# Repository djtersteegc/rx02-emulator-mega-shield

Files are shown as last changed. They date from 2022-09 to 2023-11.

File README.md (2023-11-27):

# rx02-emulator-mega-shield

Arduino Mega2560 shield with buttons and LCD based on [AK6DN's DEC RX02 emulator](https://github.com/AK6DN/rx02_emulator) board design and code.  There is a fork of his project at  https://github.com/djtersteegc/rx02_emulator that adds software support for the new board design.

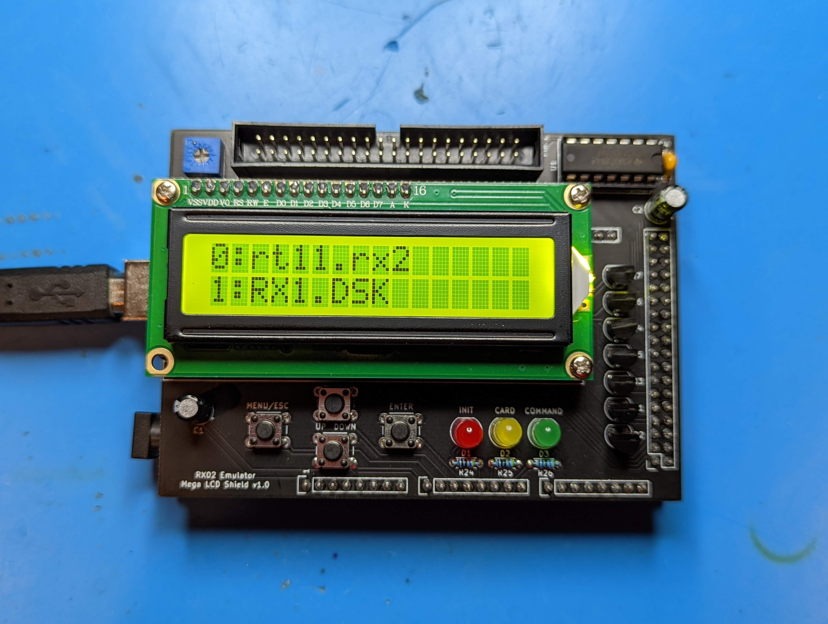
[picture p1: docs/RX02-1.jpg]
rx02-1


You can also still run it via the original serial terminal command scheme.  If you don't want to build it with the LCD or buttons, you can disable supprort in the code by leaving

`#define USE_LCD_MENU`

commented out (undefined) in `my_project.h`

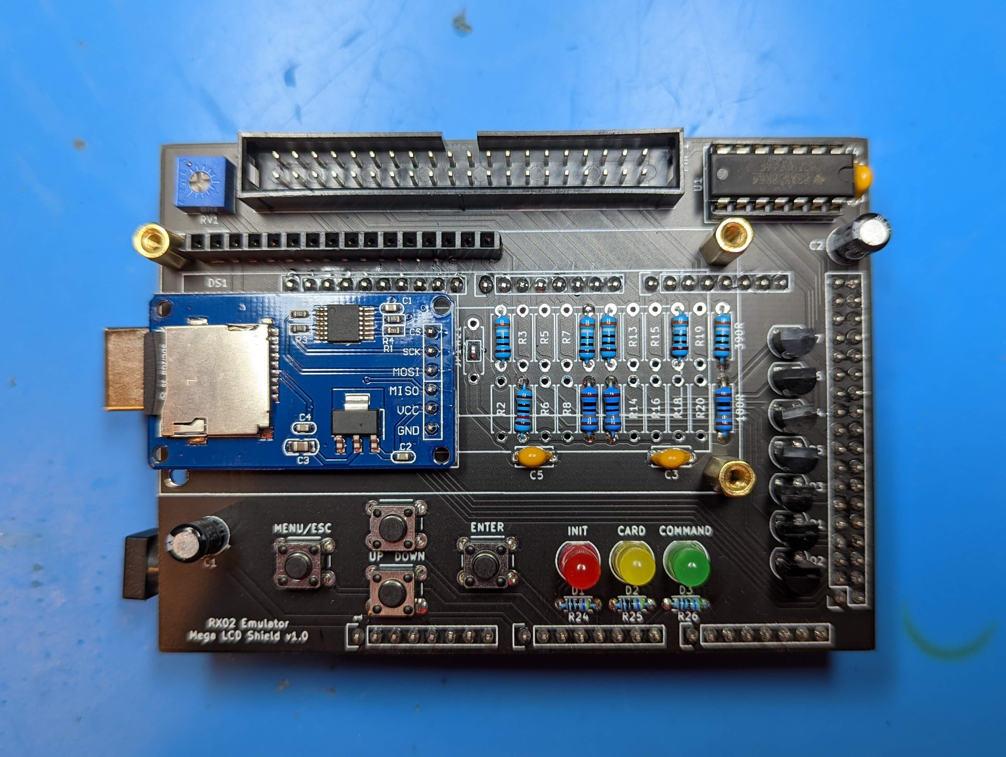
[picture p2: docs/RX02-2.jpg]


Resistor numbers is also different than AK6DN's original board so please refer to this mapping table below or the CSV file.

[Termination Resistor Table.csv](https://github.com/djtersteegc/rx02-emulator-mega-shield/blob/main/Termination%20Resistor%20Table.csv)

Most of the resistor footprints should NOT be populated.

| Signal | Resistor | Value | Resistor | Value |
| --- | --- | --- | --- | --- |
| RX_DMA_MODE_H  | R2 | - | R1 | **390** |
| RX_AC_L | R4 | **120** | R3 | - |
| RX_OUT_L | R6 | - | R5 | - |
| RX_SHIFT_L | R8 | - | R7 | - |
| RX_12BIT_L | R10 | **180** | R9 | **390** |
| RX_DATA_L | R12 | **180** | R11 | **390** |
| RX_DONE_L | R14 | - | R13 | - |
| RX_XFER_RQST_L | R16 | - | R15 | - |
| RX_INIT_L | R18 | - | R17 | **390** |
| RX_ERROR_L | R20 | - | R19 | - |
| RX_RUN_L | R23 | **180** | R22 | **390** |

STL's and the [DesignSpark Mechanical](https://www.rs-online.com/designspark/mechanical-software) source file for an snap fit enclosure are in the **enclosure** directory. There is also a provision to secure it with one M3x6mm (or longer) screw if you want.  Since the power and USB port spacing on the Chinese clone Arduino Mega2560's with the CH340 serial chip is different than the original design there are two STL's for the case body, pick the one that matches your board.

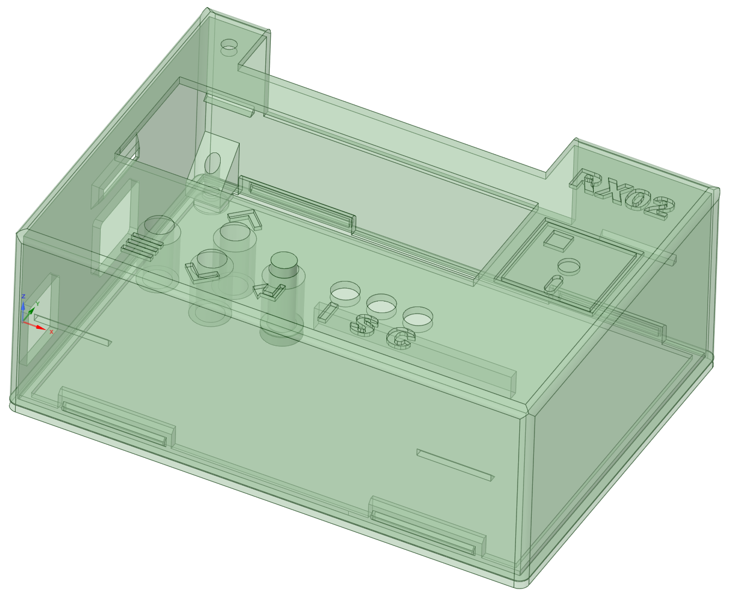
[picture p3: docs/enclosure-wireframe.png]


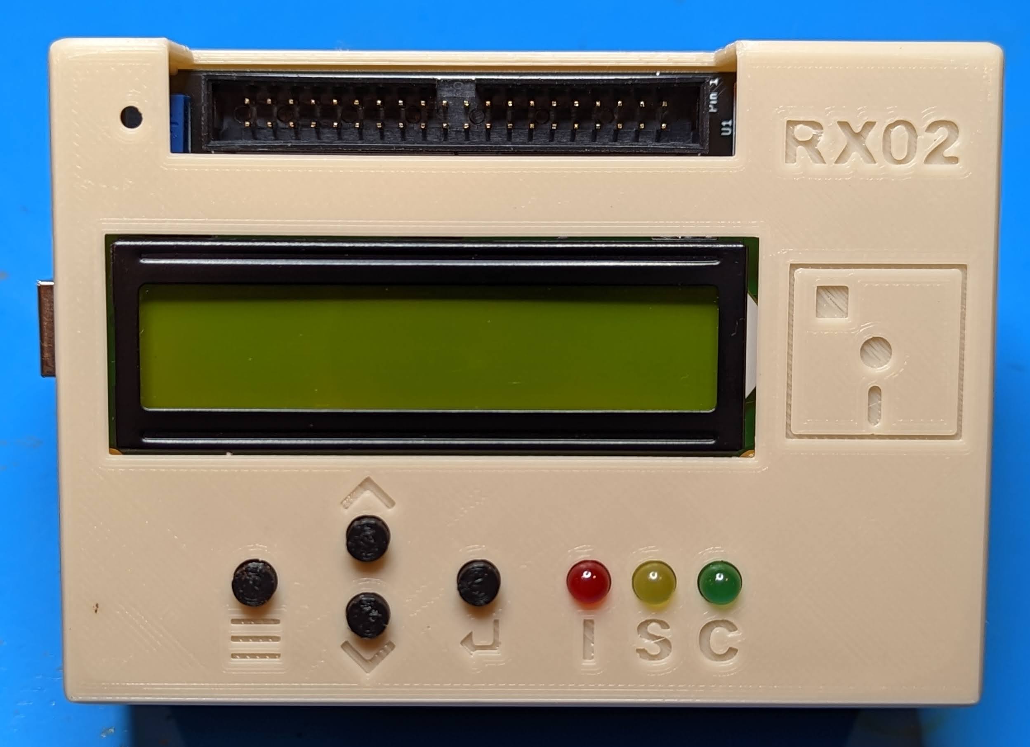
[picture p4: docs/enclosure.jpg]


All components can be sourced from the usual low cost China based vendors for a total build cost of around $20.  Please see the assembly page for more details.

[Hardware Component Choices and Assembly](https://djtersteegc.github.io/rx02-emulator-mega-shield/assembly.html)

An interactive BOM and parts placement diagram is also available.

[Interactive Bill of Materials (BOM)](https://djtersteegc.github.io/rx02-emulator-mega-shield/ibom.html)

# Getting a Board

You can download the Gerbers and use your favorite fab (JLCPCB, PCBWay, etc.) to make your own batch.  It's a standard two layer, 1oz copper board with dimensions of 99mm x 71mm so it squeaks under the 100mm x 100mm limit of the cheap Chinese fabs.

# Hardware Revisions

### Version 1.0

After designing and building the [Mega Pro SMD](https://github.com/djtersteegc/rx02-mega2560-pro) version of this, I discovered the reason you always had to do a ReINIT of the emulator to get it recognized was I failed to pick interrupt enabled pins on the Mega2560 for the RX_INIT and RX_RUN lines.  This has been corrected in the v1.1 board and you can fix this yourself in v1.0 by adding two jumper  wires from D22 to D2, and D26 to D3.  Once complete, reflash with the updated version of the code at https://github.com/djtersteegc/rx02_emulator 

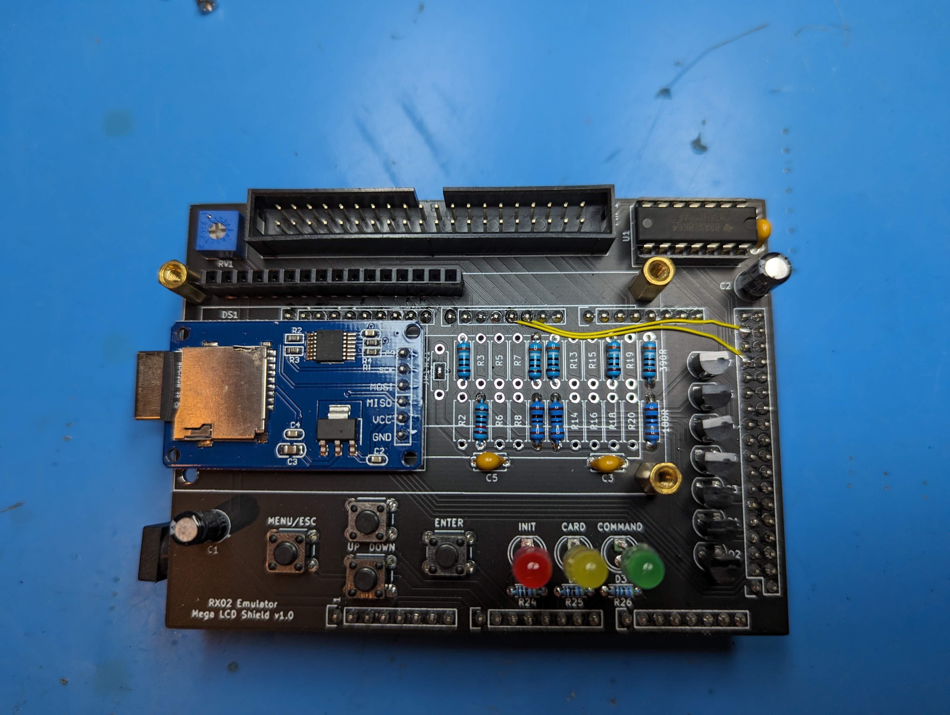
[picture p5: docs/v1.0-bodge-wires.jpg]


### Version 1.1

Moved the RX_INIT and RX_RUN lines to interrupt enabled pins on the Mega2560.

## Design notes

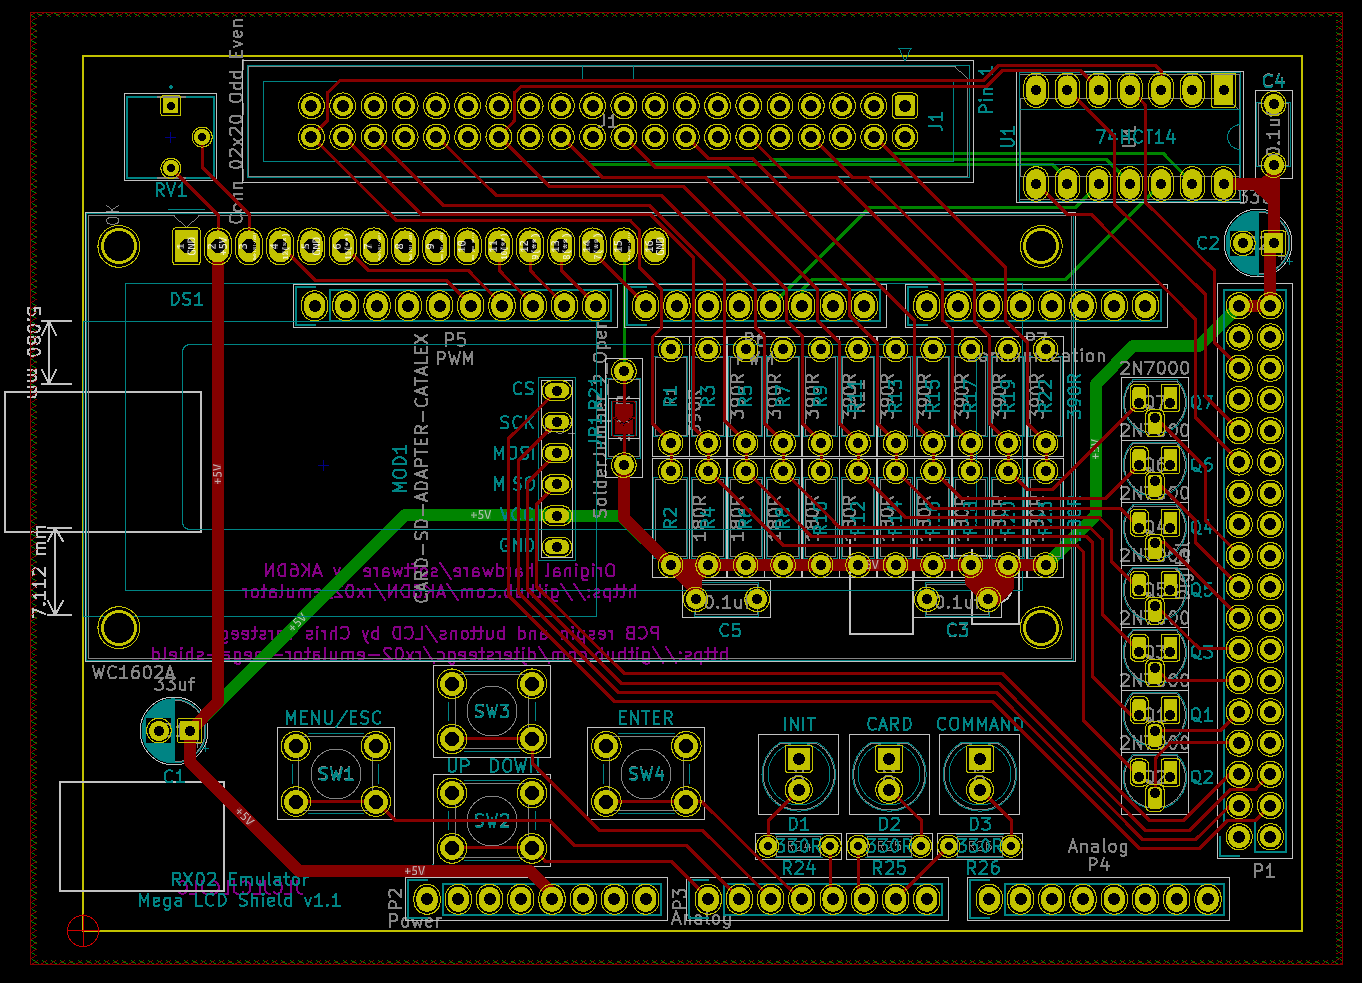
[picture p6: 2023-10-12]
Board v1.1.PNG

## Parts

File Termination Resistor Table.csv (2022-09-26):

Signal | Original Boards | LCD Board | Value
RX_DMA_MODE_H | R2 | R2 | -
 | R3 | R1 | 390
RX_AC_L | R4 | R4 | 120
 | R5 | R3 | -
RX_OUT_L | R6 | R6 | -
 | R7 | R5 | -
RX_SHIFT_L | R8 | R8 | -
 | R9 | R7 | -
RX_12BIT_L | R10 | R10 | 180
 | R23 | R9 | 390
RX_DATA_L | R11 | R12 | 180
 | R12 | R11 | 390
RX_DONE_L | R13 | R14 | -
 | R14 | R13 | -
RX_XFER_RQST_L | R15 | R16 | -
 | R16 | R15 | -
RX_INIT_L | R17 | R18 | -
 | R18 | R17 | 390
RX_ERROR_L | R19 | R20 | -
 | R20 | R19 | -
RX_RUN_L | R21 | R23 | 180
 | R22 | R22 | 390

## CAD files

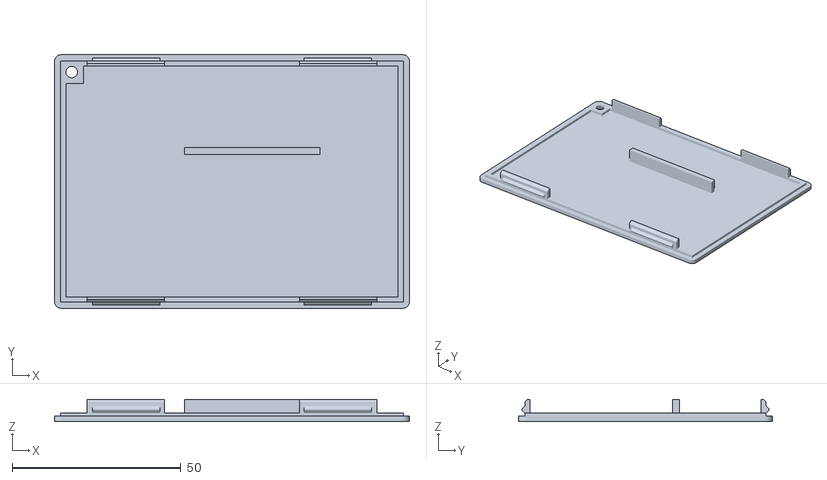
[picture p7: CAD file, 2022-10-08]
enclosure/rx02 lid.stl
105.2 x 75.1 x 6.60

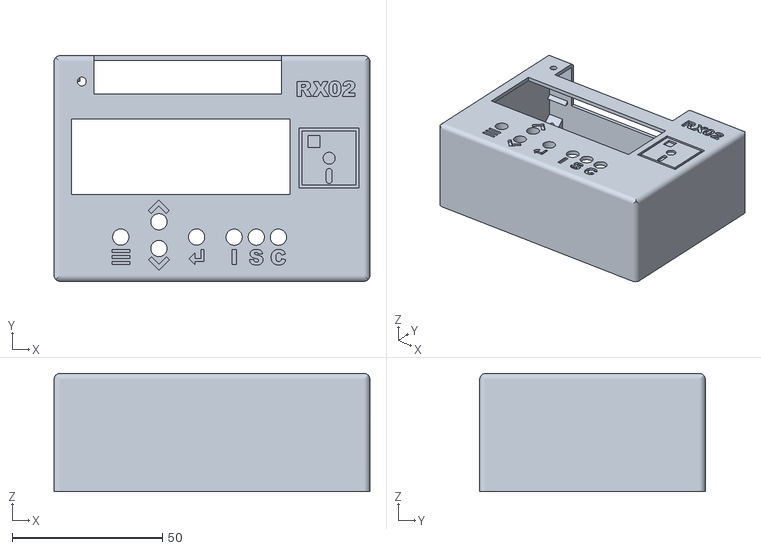
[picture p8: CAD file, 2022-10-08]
enclosure/rx02 body.stl
105.2 x 75.1 x 39.3

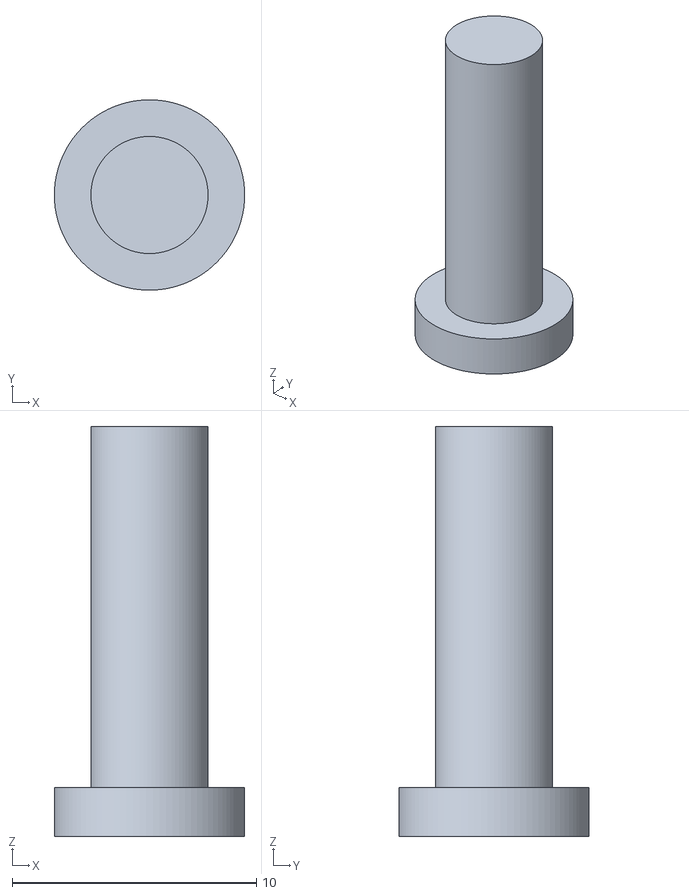
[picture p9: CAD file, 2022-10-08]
enclosure/rx02 button.stl
7.80 x 7.80 x 16.8

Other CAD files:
enclosure/rx02 body - ch340 clone.stl

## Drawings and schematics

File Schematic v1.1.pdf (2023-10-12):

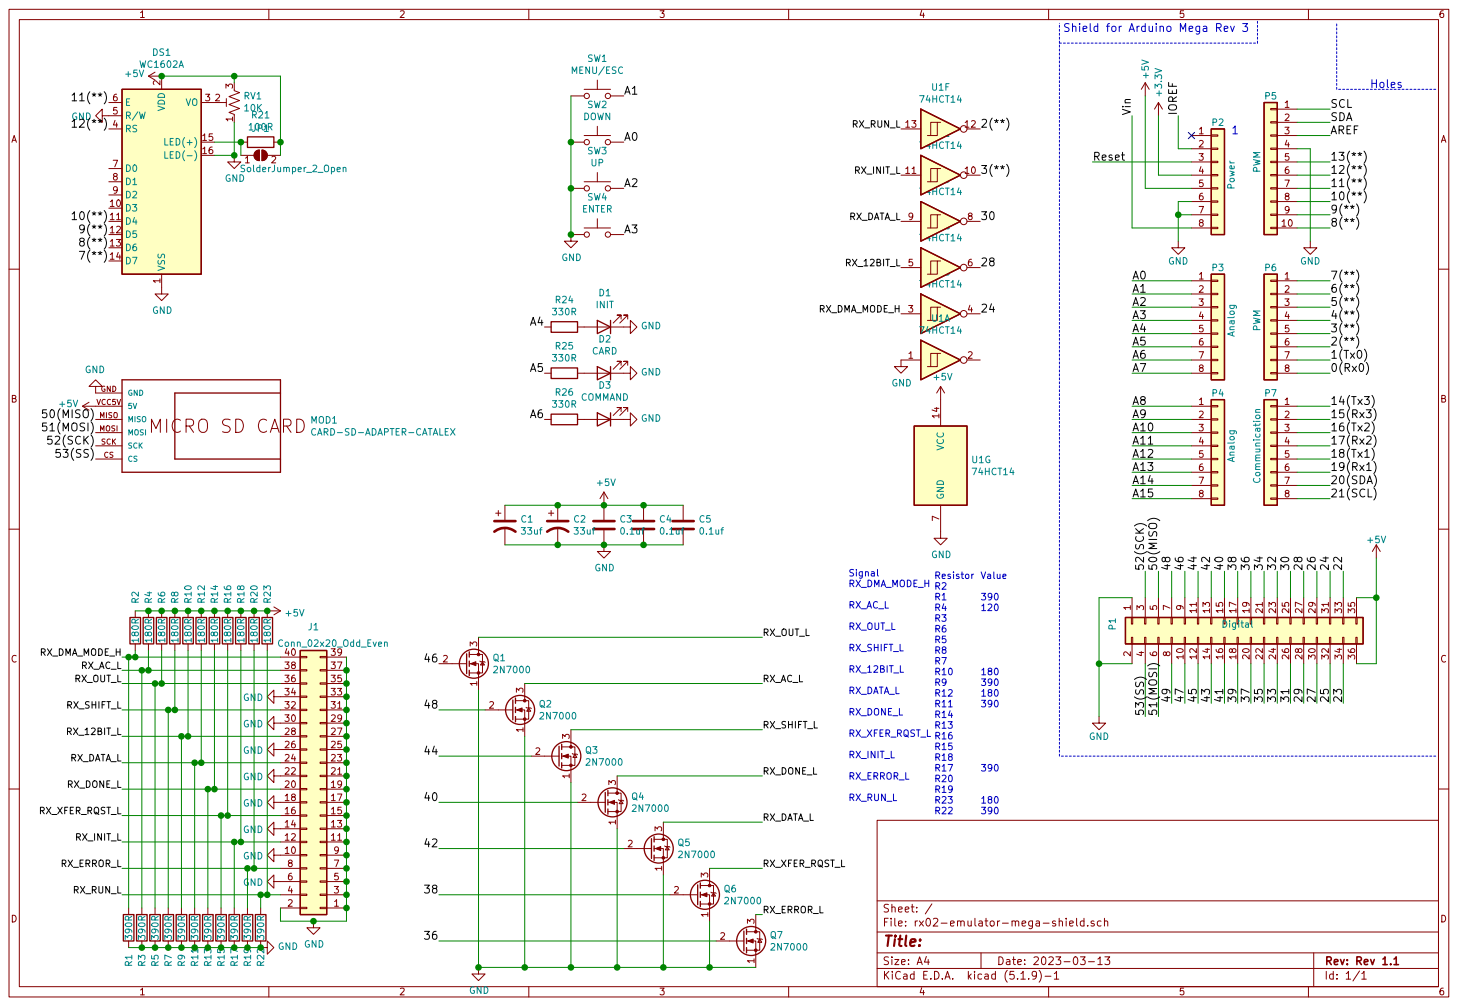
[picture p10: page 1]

38 | 37
36 | 35
34 | 33

File: rx02-emulator-mega-shield.sch Sheet: /
Id: 1/1 Title:

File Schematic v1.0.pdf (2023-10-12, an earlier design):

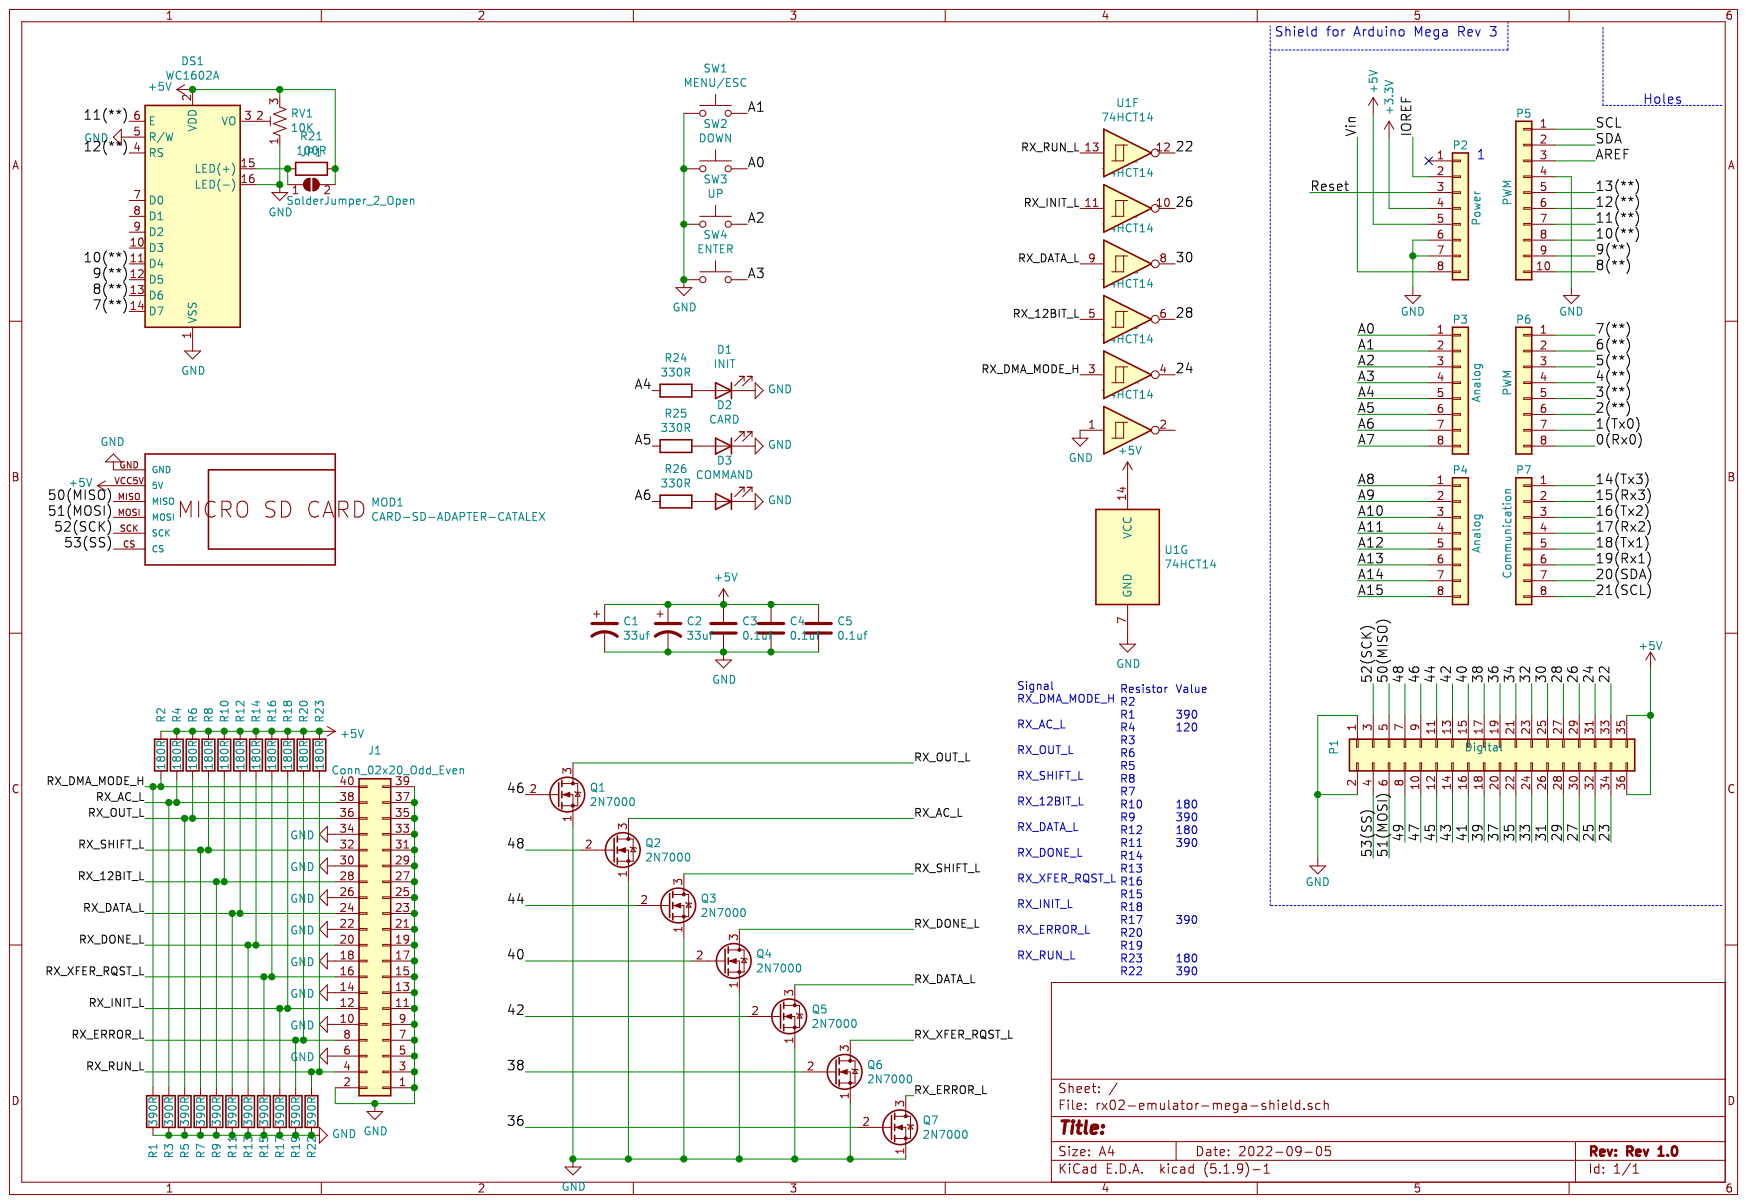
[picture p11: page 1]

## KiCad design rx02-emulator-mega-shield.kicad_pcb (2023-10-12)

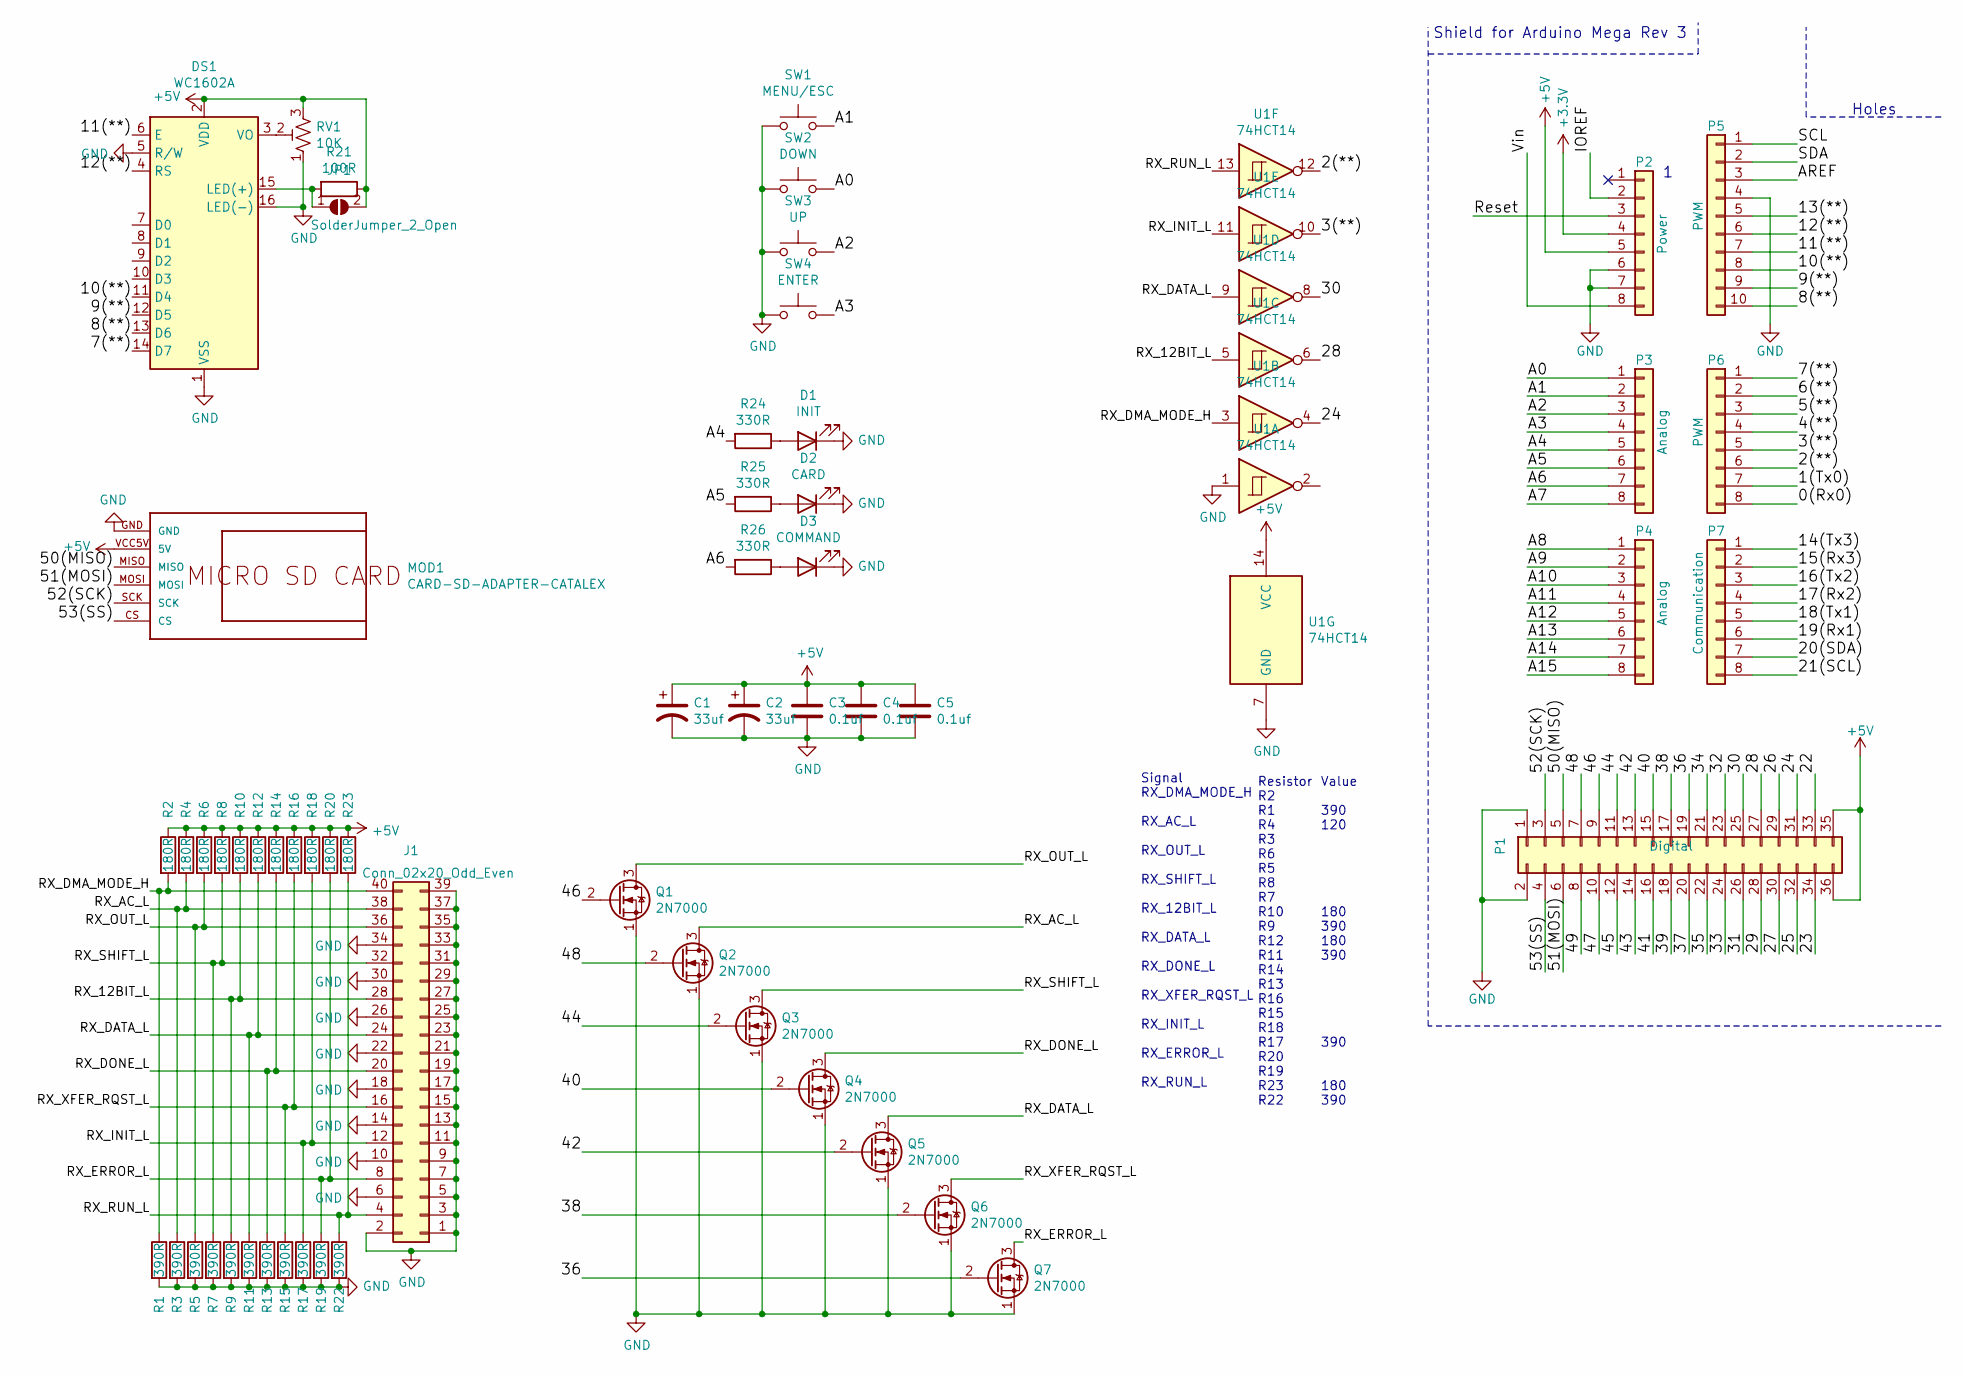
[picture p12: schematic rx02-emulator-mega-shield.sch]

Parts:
C1, C2: 33uf; CP_Radial_D5.0mm_P2.50mm
C3, C4, C5: 0.1uf; C_Disc_D5.0mm_W2.5mm_P5.00mm
D1: INIT; LED_D5.0mm
D2: CARD; LED_D5.0mm
D3: COMMAND; LED_D5.0mm
DS1: WC1602A
J1: Conn_02x20_Odd_Even; IDC-Header_2x20_P2.54mm_Vertical
JP1: SolderJumper_2_Open; SolderJumper-2_P1.3mm_Open_TrianglePad1.0x1.5mm
MOD1: CARD-SD-ADAPTER-CATALEX; Catalex-MicroSD-Card-Up
P1: Digital; Socket_Strip_Arduino_2x18
P2: Power; Socket_Strip_Arduino_1x08
P3, P4: Analog; Socket_Strip_Arduino_1x08
P5: PWM; Socket_Strip_Arduino_1x10
P6: PWM; Socket_Strip_Arduino_1x08
P7: Communication; Socket_Strip_Arduino_1x08
Q1, Q2, Q3, Q4, Q5, Q6, Q7: 2N7000; TO-92_HandSolder
R1, R3, R5, R7, R9, R11, R13, R15, R17, R19, R22: 390R; R_Axial_DIN0207_L6.3mm_D2.5mm_P7.62mm_Horizontal
R2, R4, R6, R8, R10, R12, R14, R16, R18, R20, R23: 180R; R_Axial_DIN0207_L6.3mm_D2.5mm_P7.62mm_Horizontal
R21: 100R; R_Axial_DIN0207_L6.3mm_D2.5mm_P7.62mm_Horizontal
R24, R25, R26: 330R; R_Axial_DIN0204_L3.6mm_D1.6mm_P5.08mm_Horizontal
RV1: 10K; TRIM_3362P-1-103
SW1: MENU/ESC; SW_PUSH_6mm_H4.3mm
SW2: DOWN; SW_PUSH_6mm_H4.3mm
SW3: UP; SW_PUSH_6mm_H4.3mm
SW4: ENTER; SW_PUSH_6mm_H4.3mm
U1: 74HCT14; DIP-14_W7.62mm_Socket_LongPads

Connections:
+3V3: P2.4
+5V: C1.1, C2.1, C3.1, C4.1, C5.1, DS1.2 (VDD), JP1.2 (B), MOD1.VCC5V (5V), P1.35, P1.36, P2.5, R2.1, R4.1, R6.1, R8.1, R10.1, R12.1, R14.1, R16.1, R18.1, R20.1, R21.1, R23.1, RV1.3, U1.14 (VCC)
/0(Rx0): P6.8
/1(Tx0): P6.7
/2(**): P6.6, U1.12
/3(**): P6.5, U1.10
/4(**): P6.4
/5(**): P6.3
/6(**): P6.2
/7(**): DS1.14 (D7), P6.1
/8(**): DS1.13 (D6), P5.10
/9(**): DS1.12 (D5), P5.9
/10(**): DS1.11 (D4), P5.8
/11(**): DS1.6 (E), P5.7
/12(**): DS1.4 (RS), P5.6
/13(**): P5.5
/14(Tx3): P7.1
/15(Rx3): P7.2
/16(Tx2): P7.3
/17(Rx2): P7.4
/18(Tx1): P7.5
/19(Rx1): P7.6
/20(SDA): P7.7
/21(SCL): P7.8
/22: P1.33
/23: P1.34
/24: P1.31, U1.4
/25: P1.32
/26: P1.29
/27: P1.30
/28: P1.27, U1.6
/29: P1.28
/30: P1.25, U1.8
/31: P1.26
/32: P1.23
/33: P1.24
/34: P1.21
/35: P1.22
/36: P1.19, Q7.2 (G)
/37: P1.20
/38: P1.17, Q6.2 (G)
/39: P1.18
/40: P1.15, Q4.2 (G)
/41: P1.16
/42: P1.13, Q5.2 (G)
/43: P1.14
/44: P1.11, Q3.2 (G)
/45: P1.12
/46: P1.9, Q1.2 (G)
/47: P1.10
/48: P1.7, Q2.2 (G)
/49: P1.8
/50(MISO): MOD1.MISO, P1.5
/51(MOSI): MOD1.MOSI, P1.6
/52(SCK): MOD1.SCK, P1.3
/53(SS): MOD1.CS, P1.4
/A0: P3.1, SW2.2
/A1: P3.2, SW1.2
/A2: P3.3, SW3.2
/A3: P3.4, SW4.2
/A4: P3.5, R24.2
/A5: P3.6, R25.2
/A6: P3.7, R26.2
/A7: P3.8
/A8: P4.1
/A9: P4.2
/A10: P4.3
/A11: P4.4
/A12: P4.5
/A13: P4.6
/A14: P4.7
/A15: P4.8
/AREF: P5.3
/IOREF: P2.2
/RX_12BIT_L: J1.28, R9.1, R10.2, U1.5
/RX_AC_L: J1.38, Q2.3 (D), R3.1, R4.2
/RX_DATA_L: J1.24, Q5.3 (D), R11.1, R12.2, U1.9
/RX_DMA_MODE_H: J1.40, R1.1, R2.2, U1.3
/RX_DONE_L: J1.20, Q4.3 (D), R13.1, R14.2
/RX_ERROR_L: J1.8, Q7.3 (D), R19.1, R20.2
/RX_INIT_L: J1.12, R17.1, R18.2, U1.11
/RX_OUT_L: J1.36, Q1.3 (D), R5.1, R6.2
/RX_RUN_L: J1.4, R22.1, R23.2, U1.13
/RX_SHIFT_L: J1.32, Q3.3 (D), R7.1, R8.2
/RX_XFER_RQST_L: J1.16, Q6.3 (D), R15.1, R16.2
/Reset: P2.3
/SCL: P5.1
/SDA: P5.2
/Vin: P2.8
GND: C1.2, C2.2, C3.2, C4.2, C5.2, D1.1 (K), D2.1 (K), D3.1 (K), DS1.1 (VSS), DS1.5 (R/W), DS1.16 (LED(-)), J1.1, J1.2, J1.3, J1.5, J1.6, J1.7, J1.9, J1.10, J1.11, J1.13, J1.14, J1.15, J1.17, J1.18, J1.19, J1.21, J1.22, J1.23, J1.25, J1.26, J1.27, J1.29, J1.30, J1.31, J1.33, J1.34, J1.35, J1.37, J1.39, MOD1.GND, P1.1, P1.2, P2.6, P2.7, P5.4, Q1.1 (S), Q2.1 (S), Q3.1 (S), Q4.1 (S), Q5.1 (S), Q6.1 (S), Q7.1 (S), R1.2, R3.2, R5.2, R7.2, R9.2, R11.2, R13.2, R15.2, R17.2, R19.2, R22.2, RV1.1, SW1.1, SW2.1, SW3.1, SW4.1, U1.1, U1.7 (GND)
unnamed: D1.2 (A), R24.1
unnamed: D2.2 (A), R25.1
unnamed: D3.2 (A), R26.1
unnamed: DS1.3 (VO), RV1.2
unnamed: DS1.15 (LED(+)), JP1.1 (A), R21.2

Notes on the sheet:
Shield for Arduino Mega Rev 3
Holes
Signal RX_DMA_MODE_H RX_AC_L RX_OUT_L RX_SHIFT_L RX_12BIT_L RX_DATA_L RX_DONE_L RX_XFER_RQST_L RX_INIT_L RX_ERROR_L RX_RUN_L
Resistor R2 R1 R4 R3 R6 R5 R8 R7 R10 R9 R12 R11 R14 R13 R16 R15 R18 R17 R20 R19 R23 R22
Value 390 120 180 390 180 390 390 180 390

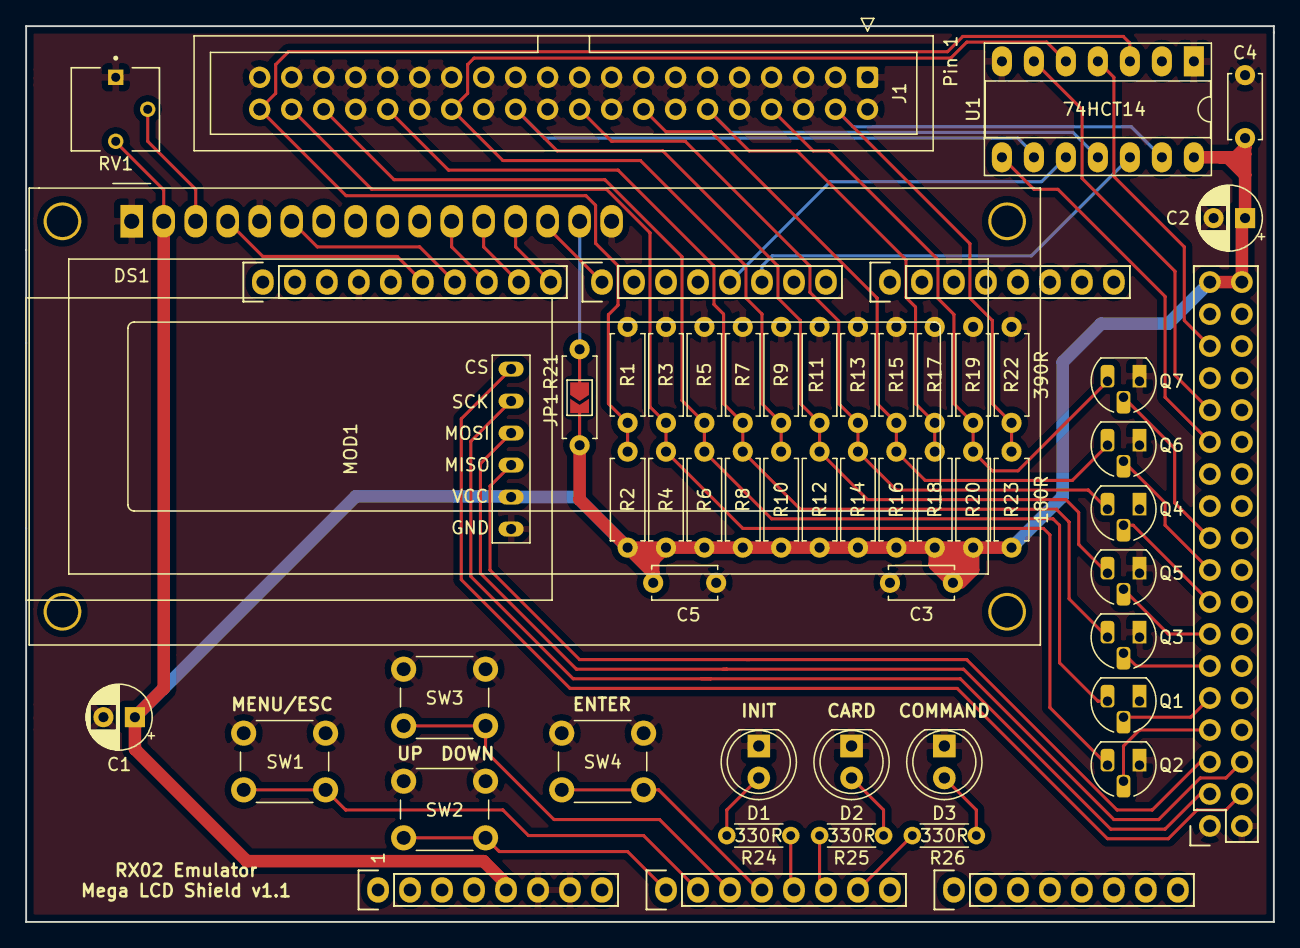
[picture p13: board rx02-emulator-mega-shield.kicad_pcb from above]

Board: 2 copper layers, 99.1 x 71.1 mm, 58 parts (0 on the bottom side), 47 nets.

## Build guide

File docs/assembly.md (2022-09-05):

# Hardware Component Choices and Assembly

[Interactive Bill of Materials (BOM)](ibom.html)

### LCD and Mounting

Any old HD44780 1602 LCD from Aliexpress/eBay for ~$2.  You do not need the I2C module, LCD is connected in 4bit parallel mode. For the stand-off mounts you need [11mm M2.5 spacers](https://www.aliexpress.com/item/1005001478740318.html) and screws (same as used mount a Raspberry Pi hat)

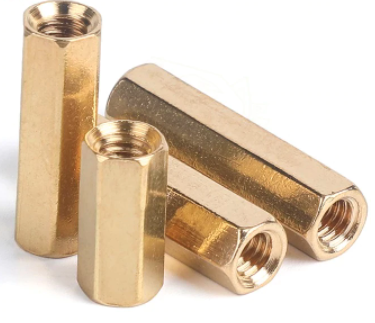
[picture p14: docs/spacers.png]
spacers
 

and a 16 pin (16p) female header.  I buy the  [40 pin packs](https://www.aliexpress.com/item/32724478308.html) and cut them down.

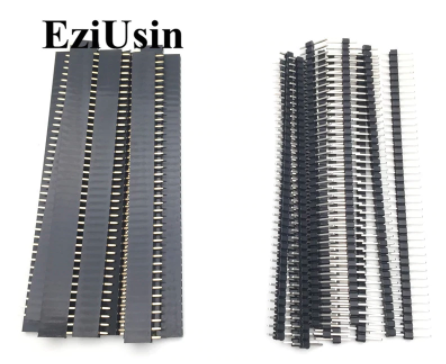
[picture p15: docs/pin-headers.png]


### Micro SD Card Connector

This is the common push-push [Micro SD module](https://www.aliexpress.com/item/1873549637.html) with level shifters.  Sometimes it may say "Catalex" (maybe the original designer?) on the back of the PCB.  You will need to remove the pre-soldered right angle header they all seem to come with so you can mount it upside down on the ADE shield board.

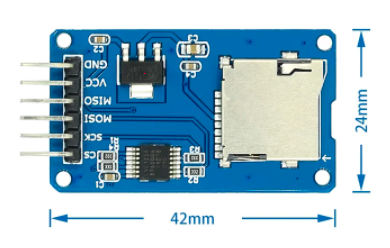
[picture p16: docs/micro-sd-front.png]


### Arduino Pin Headers

The BOM shows stacking Arudino socket strip headers since that's what was in the Kicad Mega shield template, but since you are not going to stack anything on this shield, just use the standard [2.54mm male pin headers](https://www.aliexpress.com/item/32724478308.html) you see everywhere.  You can even use two 1x18 strips instead of a 2x18 for the end connector on the Mega.

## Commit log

2022-09-05 Board version 1.0
    [rx02-emulator-mega-shield-B_Cu.gbr, rx02-emulator-mega-shield-B_Mask.gbr, rx02-emulator-mega-shield-B_SilkS.gbr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]
2022-09-26 Add resistor termination table for the new board since the numbers is not the same as Don's original board
    [Termination Resistor Table.csv]
2022-10-08 Fix 3D models
    [rx02-emulator-mega-shield.kicad_pcb]
2022-10-08 Add enlosure
    [rx02 body - ch340 clone.stl, rx02 body.stl, rx02 button.stl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]
2022-10-08 Update README with enclosure and resistor table instructions
2023-10-12 Update to v1.1 board
    [rx02-emulator-mega-shield-B_Cu.gbr, rx02-emulator-mega-shield-B_Mask.gbr, rx02-emulator-mega-shield-B_SilkS.gbr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]
2023-11-26 Add resistor table to README
